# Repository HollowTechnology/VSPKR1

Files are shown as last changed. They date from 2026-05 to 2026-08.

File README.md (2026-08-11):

<center><h1>VSPKR1</h1></center>

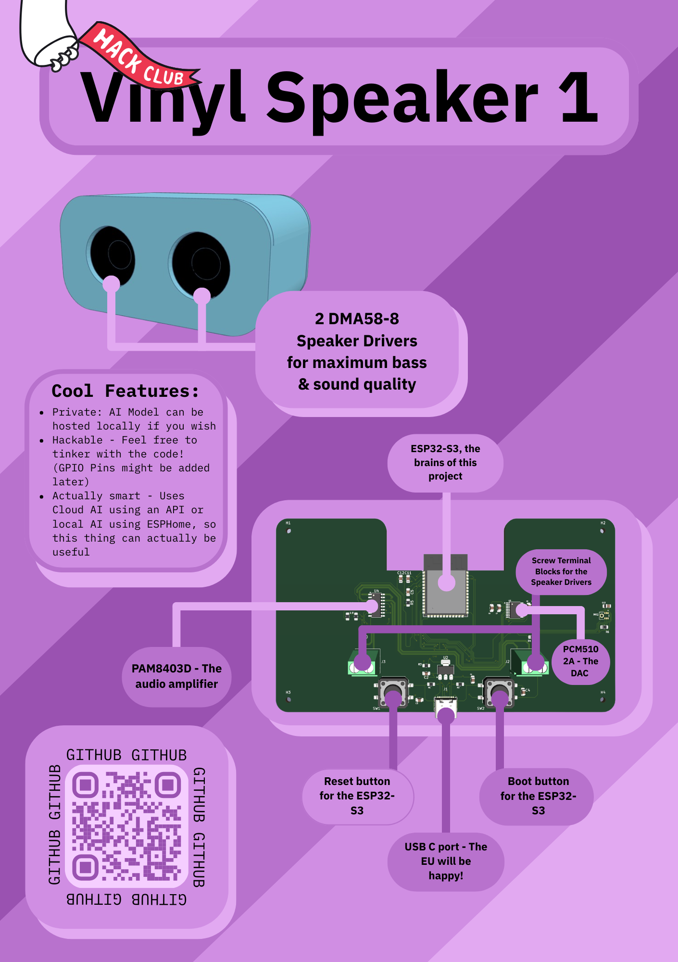
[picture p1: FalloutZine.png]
Fallout Zine


[Tinkercad URL (STL)](https://www.tinkercad.com/things/8K3mWJbN8PP-vinyl-speaker-1-case)
### What is it?

The VSPKR1 (Vinyl Speaker 1) is an open source alternative to Alexa, Google Home, or a Homepod, but open source (similar to the Home Assistant Voice Preview edition, but also made for music and not only Assist!)<br><br>
It can / will be able to be used with either cloud AI or local Ollama AI (or alternatives), making it maybe smarter than your existing smart speakers!

### Why did I decide to make this?
There are 2 reasons that I decided to make this; First, I wanted to for HackClub! Second, privacy. I have heard that Google Home speakers can spy on you, and listen in to your conversations. I think that is true 100%, so that's why I made this! To De-Google!

### A quick overview on how to build this;

> [!NOTE]
> I unfortunately got a hairline fracture on my arm while working on this project. <br>
> Sorry if this guide is bad in any way!<br>
> Also, this guide assumes you have either a hot plate or a hot air rework station

Step 1. Getting the parts<br>
All of the parts (except the PCB) are in the BOM.csv file with Digikey Part ID's for each part and quantities.<br>
Order those to get started!<br>
Make sure to also get the case 3D printed from somewhere (PCBWay can make the PCB + 3D Printed case!)
<br><br>
Step 2. Ordering PCB<br>
For this, open the `pcb` folder in the root of this repo as a project in KiCad. Then, you can export the gerber files from the `File` menu.<br>
From there, you can then order that PCB from your preferred PCB manufacturer.
<br><br>
Step 3. Build it!<br>
Once all the parts and PCB have arrived, you can then use a hot plate or hot air rework station, assuming you have one to solder all the parts to the PCB. For easier soldering, take a look at the PCB viewer in KiCad on a monitor while soldering.
<br><br>
Step 4. Flash ESPHome<br>
Follow the guide at `esphome.io` to flash the board with ESPHome firmware
<br><br>
Step 5. VSPKR1 Firmware<br>
Connect the PCB to your computer and drag and drop the `ESPHome.yaml` file from the `firmware` folder to the PCB, when it shows up as a USB Drive. You are done! Enjoy your speaker!

### Screnshots:
 



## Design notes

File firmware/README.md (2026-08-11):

<center><h1>VSPKR1 Firmware</h1></center>

### Notes about this firmware:

- This firmware is made for ESPHome, so you need to flash ESPHome on the VSPKR1 PCB, or whatever ESP32-S3 kit you use.
- This firmware is open source, so modify it as you want!

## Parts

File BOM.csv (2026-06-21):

Name | Digikey Part | Price | Quantity | Function
ESP32-S3-WROOM-1 | 5407-ESP32-S3-WROOM-1-N16R8TR-ND | $10.54 | 1 | Main brain of VSPKR1
AMS-1117-3.3t | 4518-AMS1117-3.3CT-ND | $0.47 | 1 | Voltage step down
USB4105-GF-A | 2073-USB4105-GF-ACT-ND | $1.17 | 1 | Main power input
PAM8403D | PAM8403DR-HDICT-ND | $1.25 | 1 | Audio amplifier
PCM5102A | 296-41603-5-ND | $10.85 | 1 | Amplifier controller
ICS-43432 | 1428-1053-1-ND | $5.68 | 1 | Microphone
0805 0.1uF / 100nF Capacitors | 311-3569-1-ND | $1.56 | 6 | Capacitors
0805 1uF Capacitors | 311-1365-1-ND | $0.38 | 2 | Capacitors
0805 2.2uF Capacitor | 13-AC0805KKX7RGBB225CT-ND | $0.91 | 1 | Capacitors
0805 22uF Capacitors | 311-1464-1-ND | $0.96 | 2 | Capacitors
0805 10uF Capacitor | 13-CC0805KPX5R6BB106CT-ND | $0.26 | 1 | Capacitors
0805 1K Resistor | 541-1.00KCCT-ND | $0.16 | 1 | Resistors
0805 5.1K Resistors | 1712-CPF-A-0805B5K1ECT-ND | $0.84 | 2 | Resistors
0805 10K Resistor | 311-10.0KCRCT-ND | $0.64 | 4 | Resistors
0805 100k Resistor | 541-3552-1-ND | $0.34 | 1 | Resistors
2x1 Terminal Block | 277-1258-ND | $1.7 | 2 | Terminal Block for Speakers
Speaker Drivers | https://tinyurl.com/dma58-4-2 | $18.99 | 2 | Speaker Driver
Total Cost |  | $89.29

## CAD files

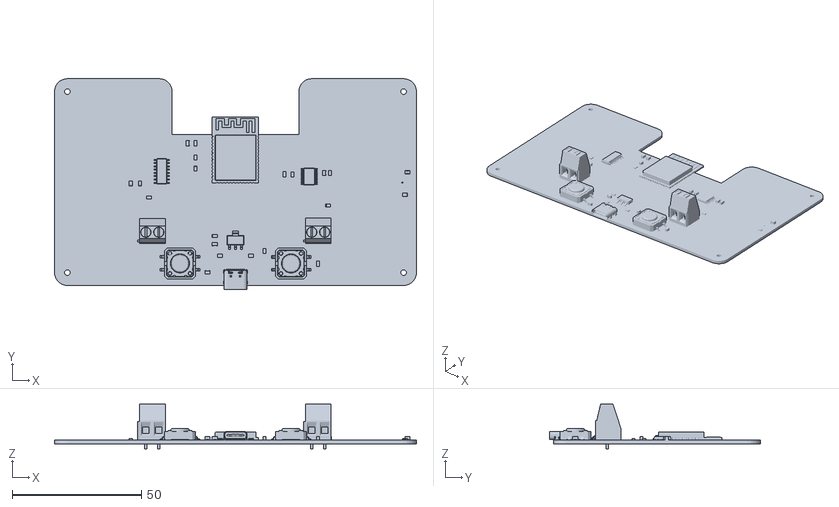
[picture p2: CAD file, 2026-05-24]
pcb/vspkr1.stl
140.0 x 81.5 x 17.3

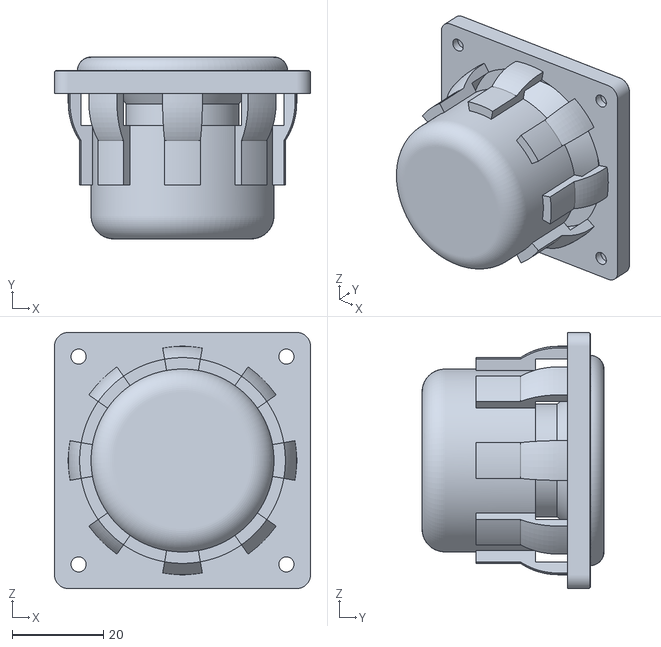
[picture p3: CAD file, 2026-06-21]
models/DMA58-8 step.stl
56.0 x 39.8 x 56.0

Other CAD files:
models/Vinyl Speaker 1 Case (Full Assembly).step
models/Vinyl Speaker 1 Case (Part 2).step
models/Vinyl Speaker 1 Case (Part 1).step
models/PCB.step
models/Vinyl Speaker 1 Case (Full Assembly).f3d
models/Vinyl Speaker 1 Case (Full Assembly).stl
models/Vinyl Speaker 1 Case (Part 1).f3d
models/Vinyl Speaker 1 Case (Part 1).stl
models/Vinyl Speaker 1 Case (Part 2).f3d
models/Vinyl Speaker 1 Case (Part 2).stl

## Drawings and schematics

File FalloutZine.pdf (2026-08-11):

# Vinyl Speaker 1

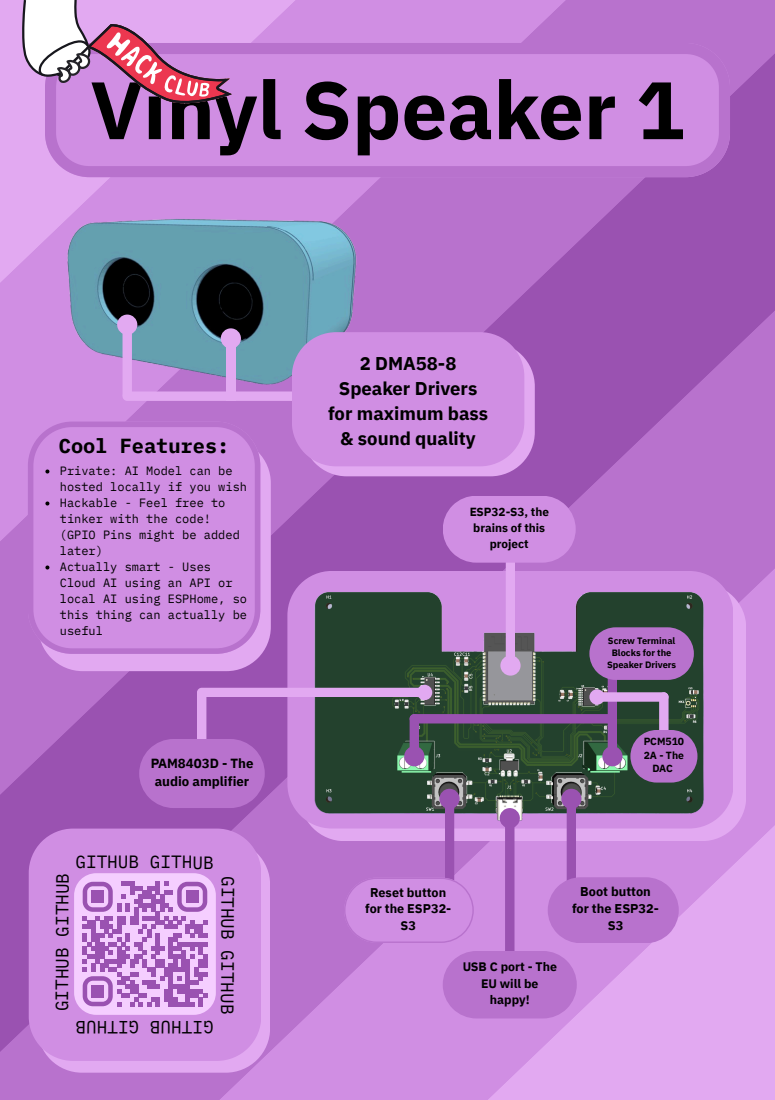
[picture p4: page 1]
Boot button for the ESP32-; Reset button; PCM510 2A - The DAC; PAM8403D - The audio amplifier

2 DMA58-8 Speaker Drivers for maximum bass

Cool Features: Private: AI Model can be hosted locally if you wish Hackable -tinker with the code! (GPIO Pins later) | Feel free to might be added

& sound quality

ESP32-S3, the | brains of this project

Actually smart - Uses
Cloud AI using an API or local AI using ESPHome, so this thing useful | can actually be

Screw Terminal
Blocks for the
Speaker Drivers

GITHUB

for the ESP32-S3 | S3

USB C port - The
EU will be
happy!

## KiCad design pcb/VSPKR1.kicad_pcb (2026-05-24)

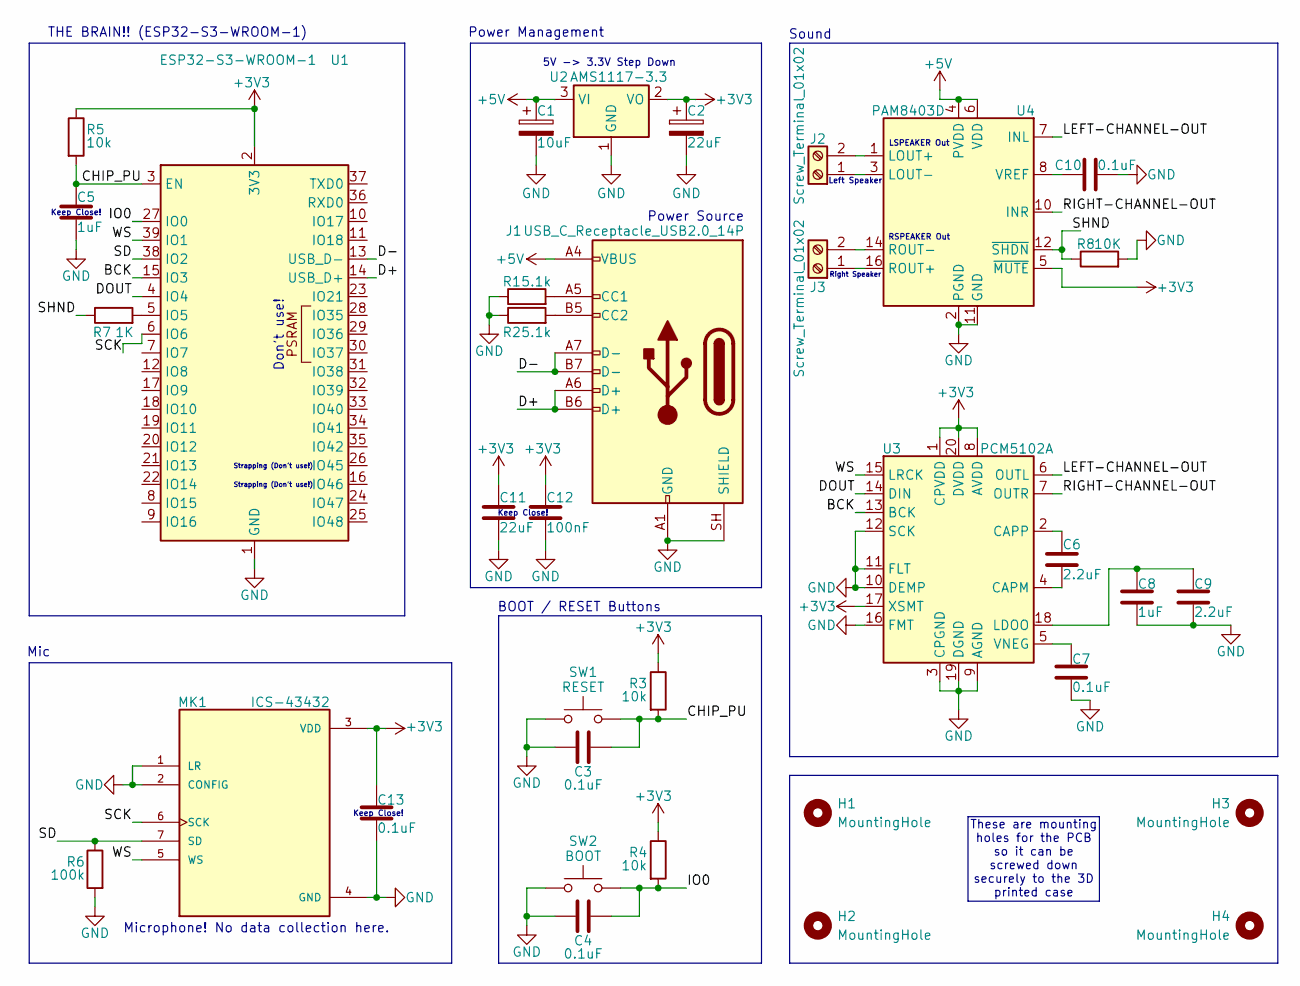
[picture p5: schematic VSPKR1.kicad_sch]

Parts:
C1: 10uF; C_0805_2012Metric_Pad1.18x1.45mm_HandSolder
C2, C11: 22uF; C_0805_2012Metric_Pad1.18x1.45mm_HandSolder
C3, C4, C7, C10, C13: 0.1uF; C_0805_2012Metric_Pad1.18x1.45mm_HandSolder
C5, C8: 1uF; C_0805_2012Metric_Pad1.18x1.45mm_HandSolder
C6, C9: 2.2uF; C_0805_2012Metric_Pad1.18x1.45mm_HandSolder
C12: 100nF; C_0805_2012Metric_Pad1.18x1.45mm_HandSolder
H1, H2, H3, H4: MountingHole; MountingHole_2.2mm_M2
J1: USB_C_Receptacle_USB2.0_14P; USB_C_Receptacle_GCT_USB4105-xx-A_16P_TopMnt_Horizontal
J2, J3: Screw_Terminal_01x02; TerminalBlock_Phoenix_MKDS-1,5-2_1x02_P5.00mm_Horizontal
MK1: ICS-43432; MIC_ICS-43432; PARTREV 1.3
R1, R2: 5.1k; R_0805_2012Metric_Pad1.20x1.40mm_HandSolder
R3, R4, R5: 10k; R_0805_2012Metric_Pad1.20x1.40mm_HandSolder
R6: 100k; R_0805_2012Metric_Pad1.20x1.40mm_HandSolder
R7: 1K; R_0805_2012Metric_Pad1.20x1.40mm_HandSolder
R8: 10K; R_0805_2012Metric_Pad1.20x1.40mm_HandSolder
SW1: RESET; SW_Push_1P1T_NO_CK_PTS125Sx43SMTR
SW2: BOOT; SW_Push_1P1T_NO_CK_PTS125Sx43SMTR
U1: ESP32-S3-WROOM-1
U2: AMS1117-3.3; SOT-223-3_TabPin2
U3: PCM5102A; TSSOP-20_4.4x6.5mm_P0.65mm
U4: PAM8403D; SOIC-16_3.9x9.9mm_P1.27mm

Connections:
+3V3: C2.1, C11.1, C12.1, C13.1, MK1.3 (VDD), R3.1, R4.1, R5.1, U1.2 (3V3), U2.2 (VO), U3.1 (CPVDD), U3.8 (AVDD), U3.17 (XSMT), U3.20 (DVDD), U4.5 (~MUTE)
+5V: C1.1, J1.A4 (VBUS), J1.A9 (VBUS), J1.B4 (VBUS), J1.B9 (VBUS), U2.3 (VI), U4.4 (PVDD), U4.6 (VDD), U4.13 (PVDD)
/BCK: U1.15 (IO3), U3.13 (BCK)
/CHIP_PU: C3.2, C5.1, R3.2, R5.2, SW1.2, U1.3 (EN)
/D+: J1.A6 (D+), J1.B6 (D+), U1.14 (USB_D+)
/D-: J1.A7 (D-), J1.B7 (D-), U1.13 (USB_D-)
/DOUT: U1.4 (IO4), U3.14 (DIN)
/IO0: C4.2, R4.2, SW2.2, U1.27 (IO0)
/LEFT-CHANNEL-OUT: U3.6 (OUTL), U4.7 (INL)
/RIGHT-CHANNEL-OUT: U3.7 (OUTR), U4.10 (INR)
/SCK: MK1.6 (SCK), U1.6 (IO6)
/SD: MK1.7 (SD), R6.1, U1.38 (IO2)
/SHND: R7.1, R8.1, U4.12 (~SHDN)
/WS: MK1.5 (WS), U1.39 (IO1), U3.15 (LRCK)
GND: C1.2, C2.2, C3.1, C4.1, C5.2, C7.2, C8.2, C9.2, C10.2, C11.2, C12.2, C13.2, J1.A1 (GND), J1.A12 (GND), J1.B1 (GND), J1.B12 (GND), J1.SH (SHIELD), MK1.1 (LR), MK1.2 (CONFIG), MK1.4 (GND), R1.1, R2.1, R6.2, R8.2, SW1.1, SW2.1, U1.1 (GND), U1.40 (GND), U1.41 (GND), U2.1 (GND), U3.3 (CPGND), U3.9 (AGND), U3.10 (DEMP), U3.11 (FLT), U3.12 (SCK), U3.16 (FMT), U3.19 (DGND), U4.2 (PGND), U4.11 (GND), U4.15 (PGND)
unnamed: J1.A5 (CC1), R1.2
unnamed: J1.B5 (CC2), R2.2
unnamed: J2.1, U4.3 (LOUT-)
unnamed: J2.2, U4.1 (LOUT+)
unnamed: J3.1, U4.16 (ROUT+)
unnamed: J3.2, U4.14 (ROUT-)
unnamed: R7.2, U1.5 (IO5)
unnamed: C6.2, U3.4 (CAPM)
unnamed: C6.1, U3.2 (CAPP)
unnamed: C8.1, C9.1, U3.18 (LDOO)
unnamed: C7.1, U3.5 (VNEG)
unnamed: C10.1, U4.8 (VREF)

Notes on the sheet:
Sound
Strapping (Don't use!)
RSPEAKER Out
Keep Close!
Power Source
BOOT / RESET Buttons
Don't use!
Microphone! No data collection here.
Mic
These are mounting holes for the PCB so it can be screwed down securely to the 3D printed case
5V -> 3.3V Step Down
Right Speaker
Power Management
Left Speaker
LSPEAKER Out
THE BRAIN!! (ESP32-S3-WROOM-1)

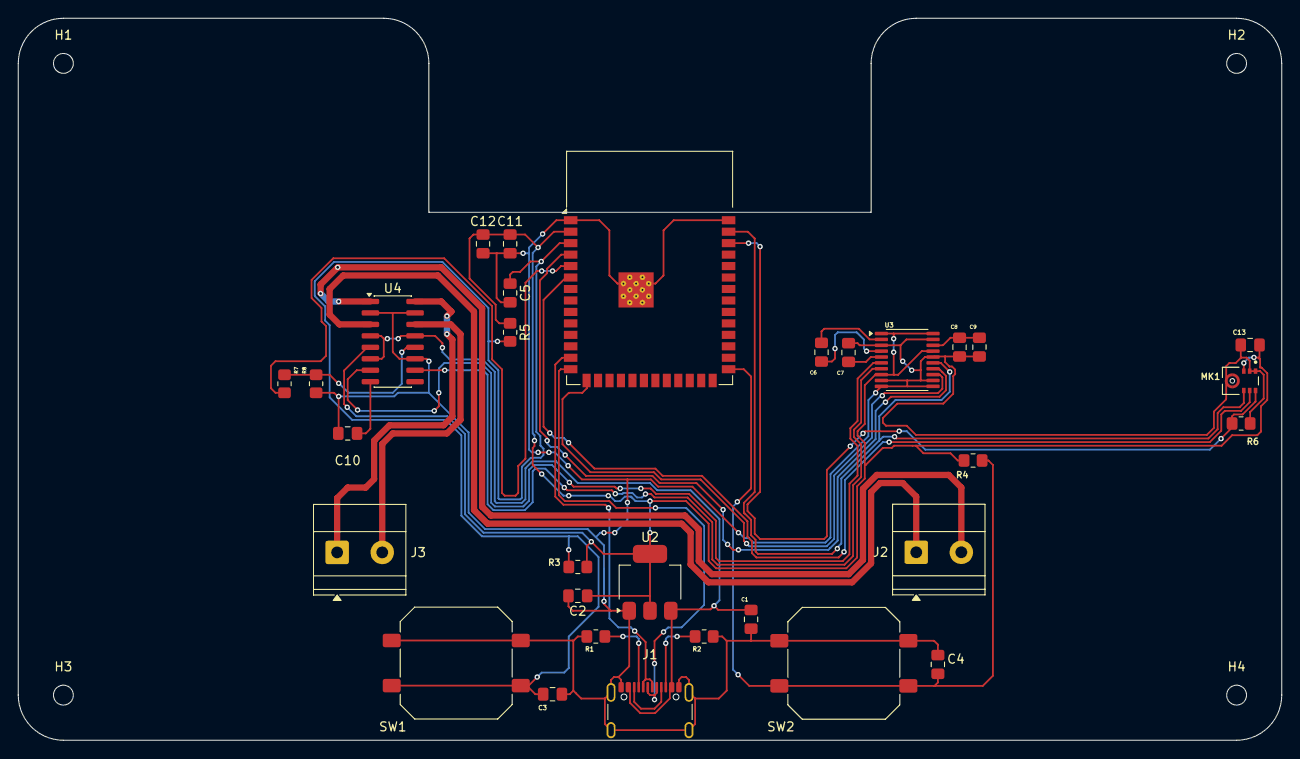
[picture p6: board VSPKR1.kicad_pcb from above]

Board: 2 copper layers, 140.0 x 80.0 mm, 35 parts (0 on the bottom side), 27 nets.

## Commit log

2026-04-18 Add PCB stuff
    [VSPKR1.kicad_pcb, VSPKR1.kicad_sch]
2026-04-18 added speaker stuffs
    but i havent actually connected it to esp32
    [VSPKR1.kicad_sch]
2026-04-22 pcb time!!111!!!!1!
    [VSPKR1.kicad_pcb, VSPKR1.kicad_sch]
2026-05-03 git push -m "hmm"
    [VSPKR1.kicad_pcb, VSPKR1.kicad_sch]
2026-05-05 Routing PCB traces
    [VSPKR1.kicad_pcb]
2026-05-24 Finished the PCB
    [VSPKR1.kicad_pcb, VSPKR1.kicad_sch, vspkr1.stl]
2026-06-17 Add speaker drivers to BOM.csv
    Added speaker drivers to the BOM with details.
    [BOM.csv]
2026-06-21 Added STL and STEP and f3d files
    [Vinyl Speaker 1 Case (Full Assembly).f3d, Vinyl Speaker 1 Case (Full Assembly).step, Vinyl Speaker 1 Case (Full Assembly).stl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]
